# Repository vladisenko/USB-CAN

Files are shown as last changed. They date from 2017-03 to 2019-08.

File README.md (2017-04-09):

# USB-CAN
Yet another USB-CAN adapter. Device based on STM32F072C8T6 mcu with USB and CAN peripherals. As the galvanic isolated CAN transceiver is used ISO1050 from TI. Boards communicate with PC by Virtual COM port with LAWICEL protocol.
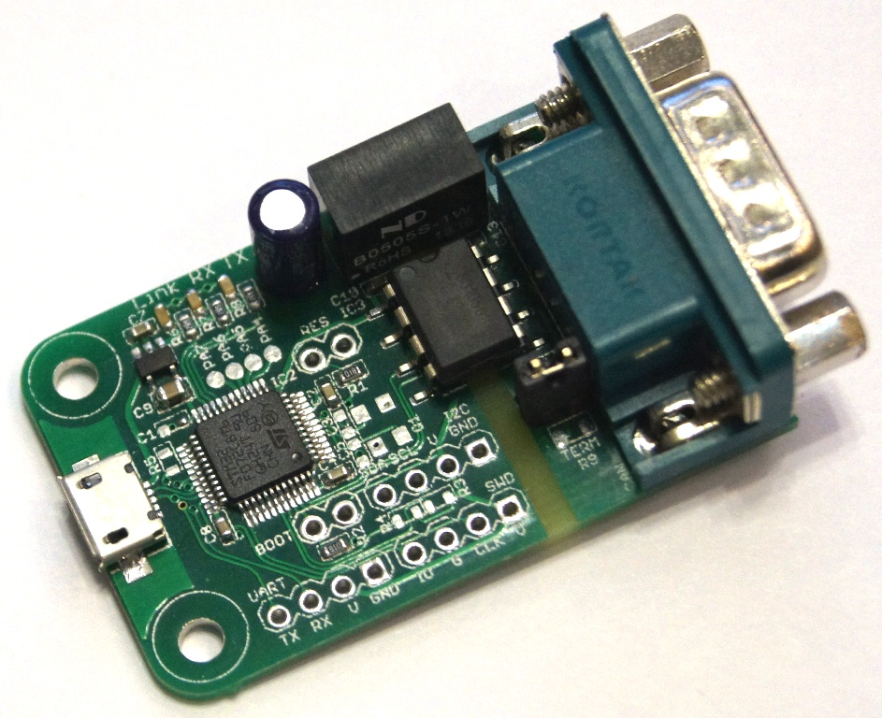
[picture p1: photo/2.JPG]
USB-CAN adapter


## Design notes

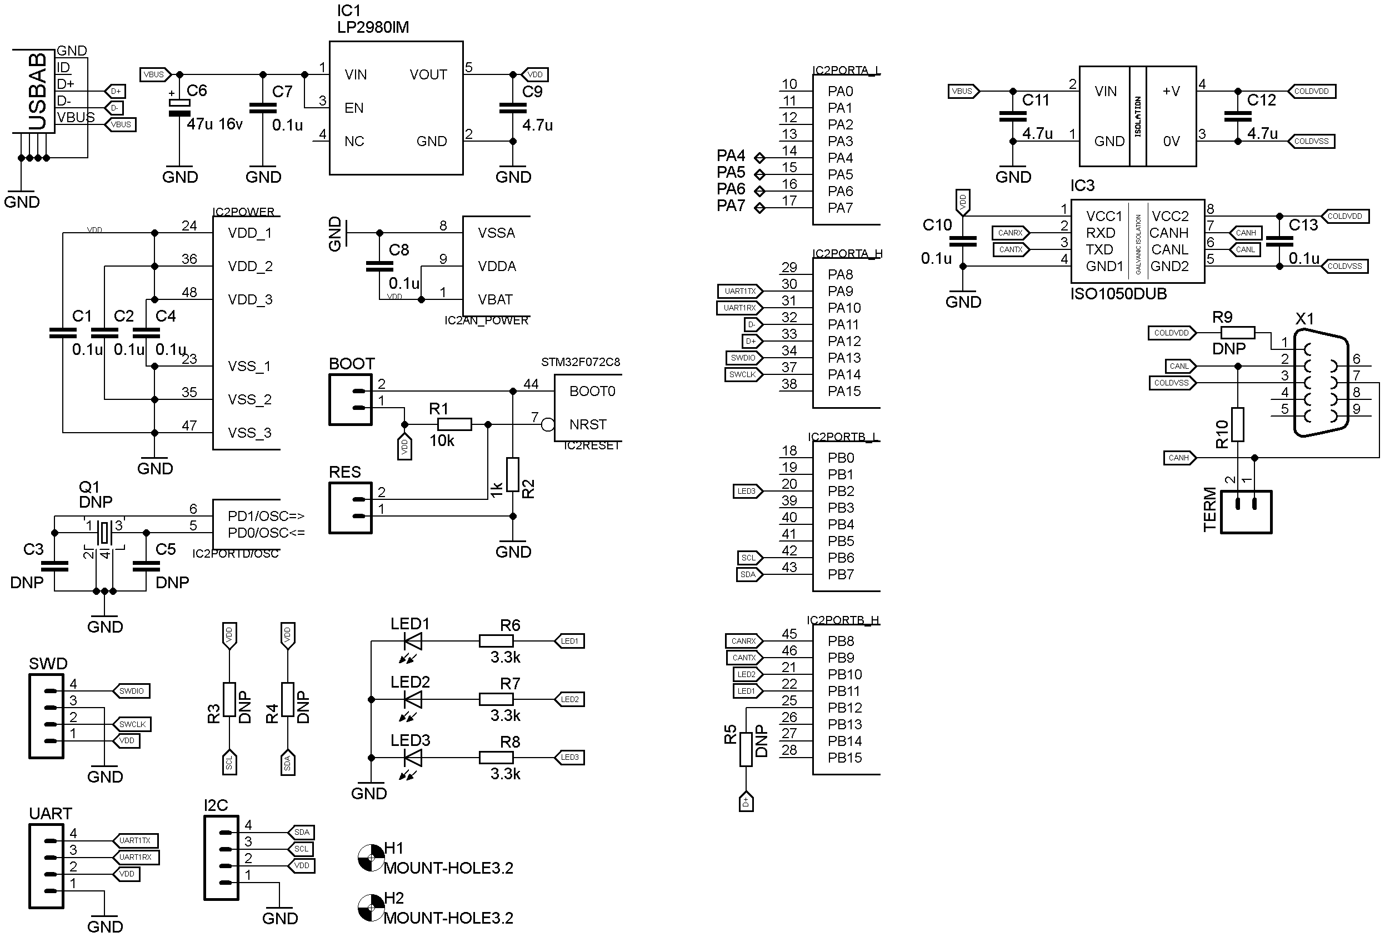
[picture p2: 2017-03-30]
hw/schematic.png

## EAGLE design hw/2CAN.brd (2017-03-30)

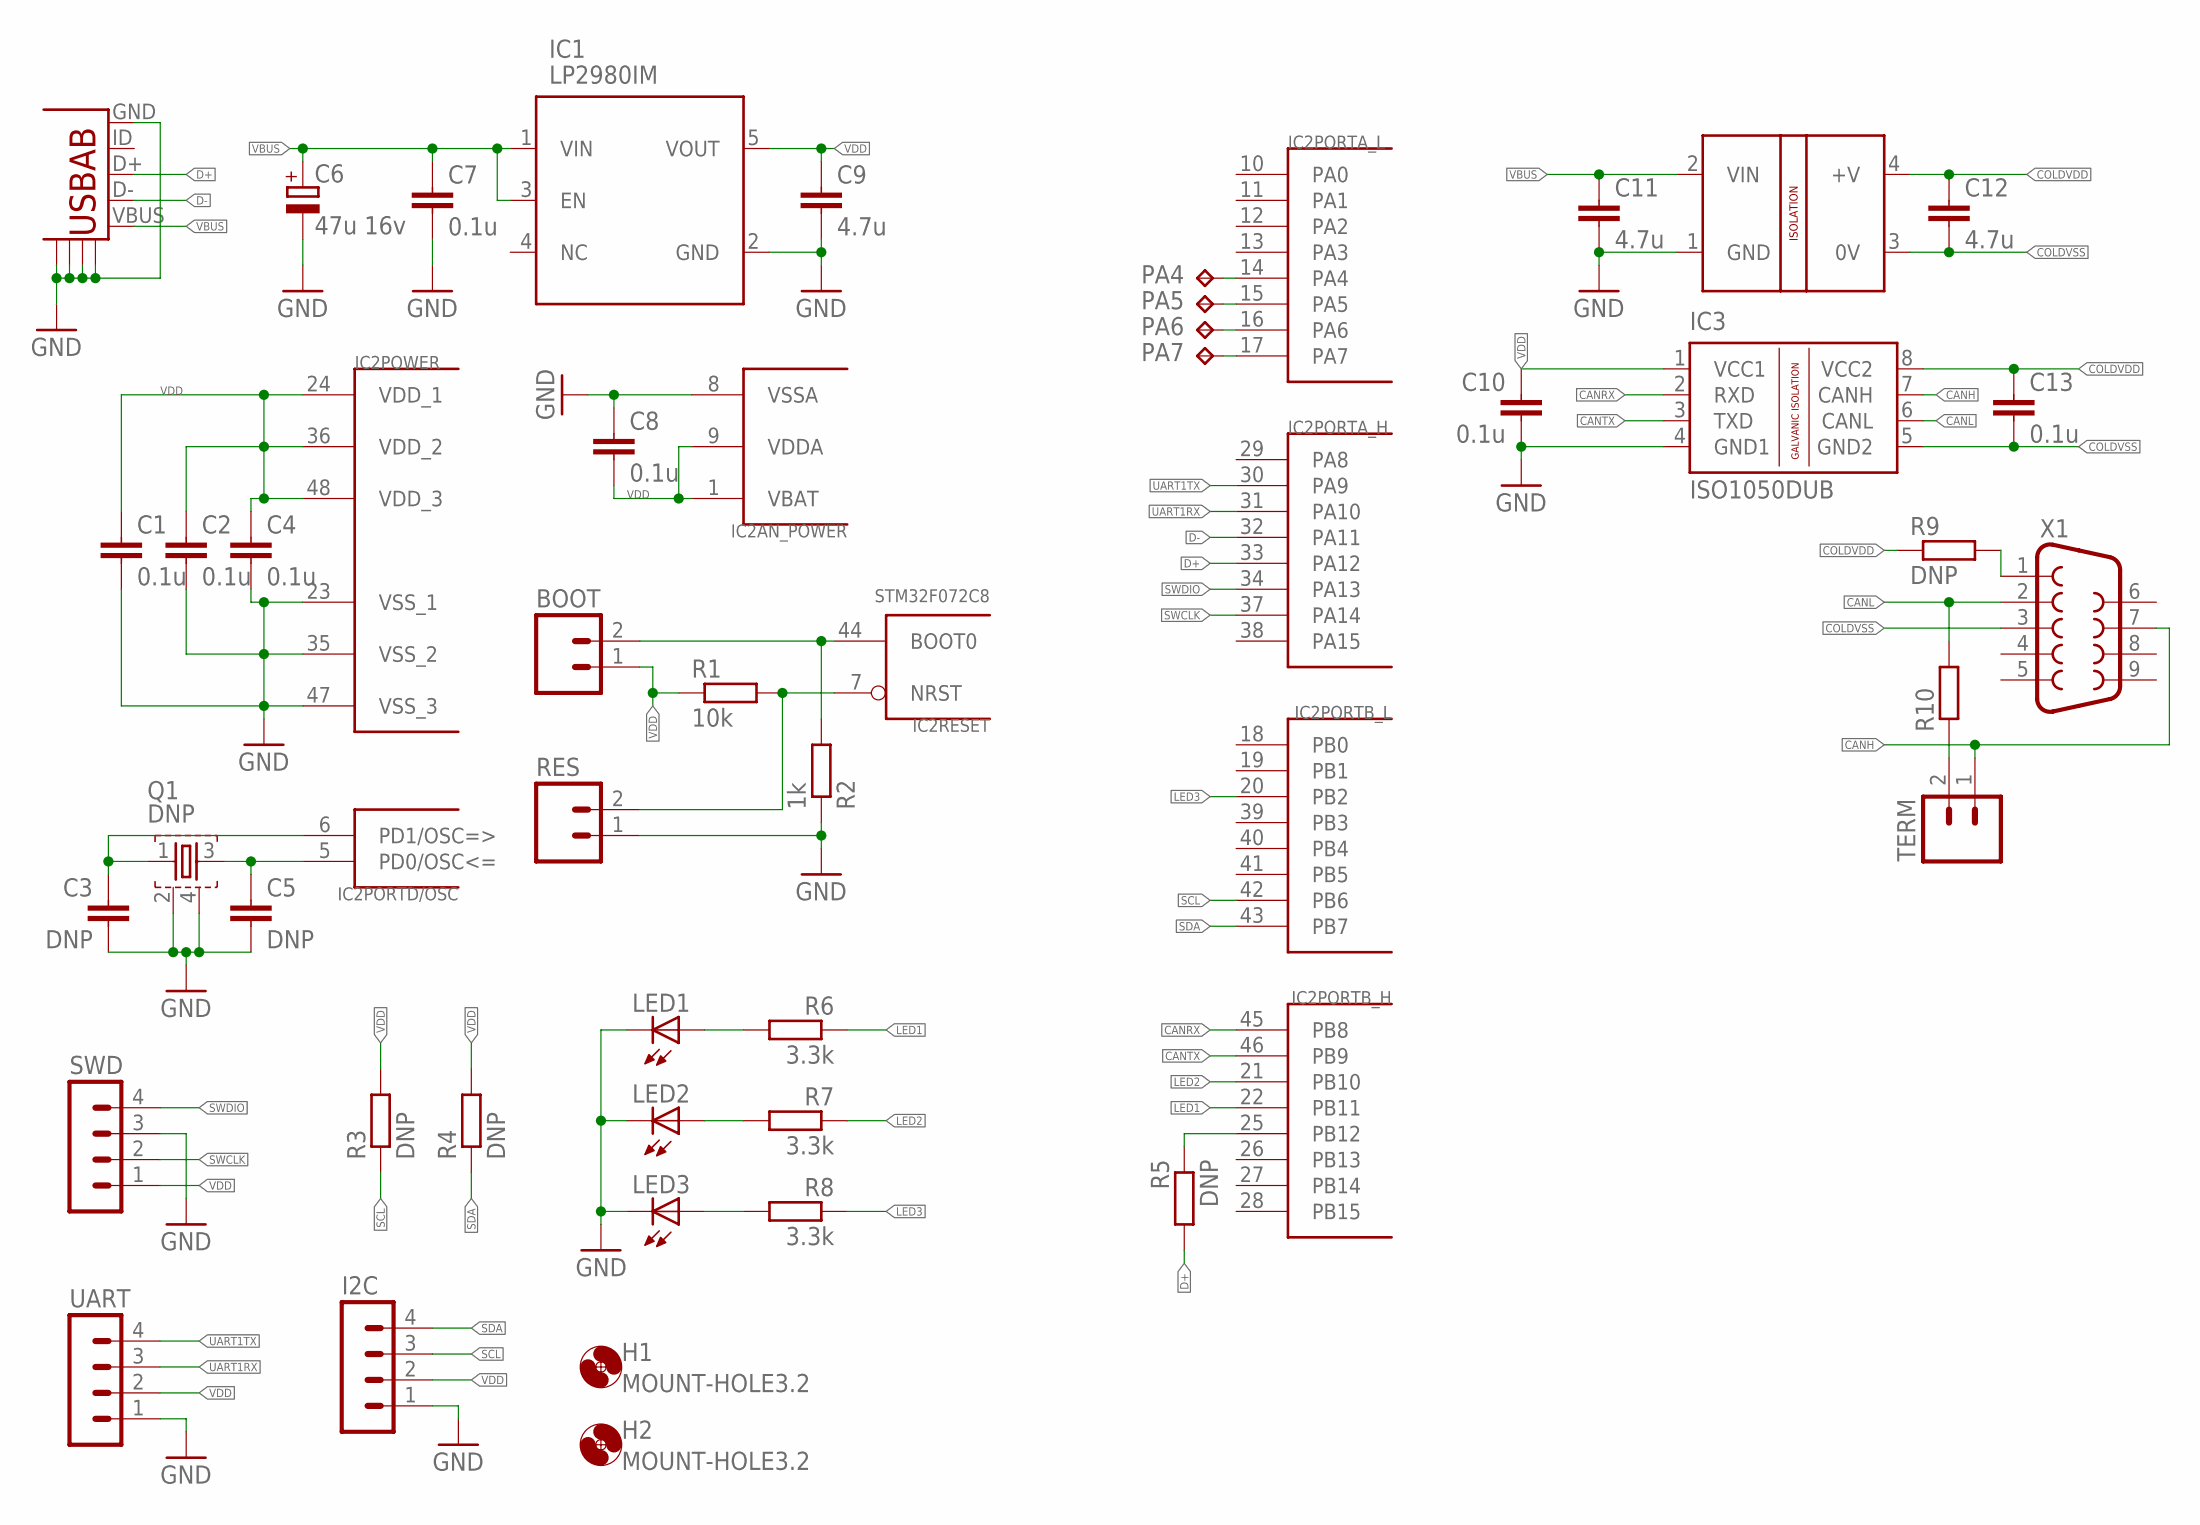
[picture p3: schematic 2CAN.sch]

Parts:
BOOT: M02PTH; 1X02
C1, C2, C4, C7, C8, C10, C13: 0.1u; C0603
C3, C5: DNP; C0603
C6: 47u 16v; E2-5
C9, C11, C12: 4.7u; C0805
H1, H2: MOUNT-HOLE3.2; 3,2
I2C: MA04-1
IC1: LP2980IM; SOT23-5L
IC2: STM32F072C8; TQFP48
IC3: ISO1050DUB; DUB-R-PDSO-G8
LED1, LED2, LED3: LEDSML0603; SML0603
PA4, PA5, PA6, PA7: TPB1,27; B1,27
Q1: DNP; FA-20H
R1: 10k; R0603
R2: 1k; R0603
R3, R4, R5: DNP; R0603
R6, R7, R8: 3.3k; R0603
R9: DNP; R0805
R10: R-EU_R0805; R0805
RES: M02PTH; 1X02
SWD: MA04-1
TERM: M02PTH; 1X02
U$1: USB_AB; USB-AB-MICRO-SMD
U$2: B0505SV; B0505S_V
UART: MA04-1
X1: DB9MALE; DB9_MALE

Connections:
CANH: IC3.7 (CANH), TERM.1, X1.7
CANL: IC3.6 (CANL), R10.2, X1.2
CANRX: IC2.45 (PB8), IC3.2 (RXD)
CANTX: IC2.46 (PB9), IC3.3 (TXD)
COLDVDD: C12.1, C13.1, IC3.8 (VCC2), R9.1, U$2.4 (+V)
COLDVSS: C12.2, C13.2, IC3.5 (GND2), U$2.3 (0V), X1.3
D+: IC2.33 (PA12), R5.2, U$1.D+
D-: IC2.32 (PA11), U$1.D-
GND: C1.2, C2.2, C3.2, C4.2, C5.2, C6.-, C7.2, C8.1, C9.2, C10.2, C11.2, I2C.1, IC1.2 (GND), IC2.8 (VSSA), IC2.23 (VSS_1), IC2.35 (VSS_2), IC2.47 (VSS_3), IC3.4 (GND1), LED1.C, LED2.C, LED3.C, Q1.2, Q1.4, R2.1, RES.1, SWD.3, U$1.GND, U$1.GND@1, U$1.GND@2, U$1.GND@3, U$1.GND@4, U$2.1 (GND), UART.1
LED1: IC2.22 (PB11), R6.1
LED2: IC2.21 (PB10), R7.1
LED3: IC2.20 (PB2), R8.1
unnamed: IC2.7 (NRST), R1.2, RES.2
unnamed: BOOT.2, IC2.44 (BOOT0), R2.2
unnamed: R9.2, X1.1
unnamed: LED1.A, R6.2
unnamed: LED2.A, R7.2
unnamed: LED3.A, R8.2
unnamed: R10.1, TERM.2
unnamed: C5.1, IC2.5 (PD0/OSC<=), Q1.3
unnamed: C3.1, IC2.6 (PD1/OSC=>), Q1.1
unnamed: IC2.14 (PA4), PA4.TP
unnamed: IC2.15 (PA5), PA5.TP
unnamed: IC2.16 (PA6), PA6.TP
unnamed: IC2.17 (PA7), PA7.TP
SCL: I2C.3, IC2.42 (PB6), R3.1
SDA: I2C.4, IC2.43 (PB7), R4.1
SWCLK: IC2.37 (PA14), SWD.2
SWDIO: IC2.34 (PA13), SWD.4
UART1RX: IC2.31 (PA10), UART.3
UART1TX: IC2.30 (PA9), UART.4
USBPU: IC2.25 (PB12), R5.1
VBUS: C6.+, C7.1, C11.1, IC1.1 (VIN), IC1.3 (EN), U$1.VBUS, U$2.2 (VIN)
VDD: BOOT.1, C1.1, C2.1, C4.1, C8.2, C9.1, C10.1, I2C.2, IC1.5 (VOUT), IC2.1 (VBAT), IC2.9 (VDDA), IC2.24 (VDD_1), IC2.36 (VDD_2), IC2.48 (VDD_3), IC3.1 (VCC1), R1.1, R3.2, R4.2, SWD.1, UART.2

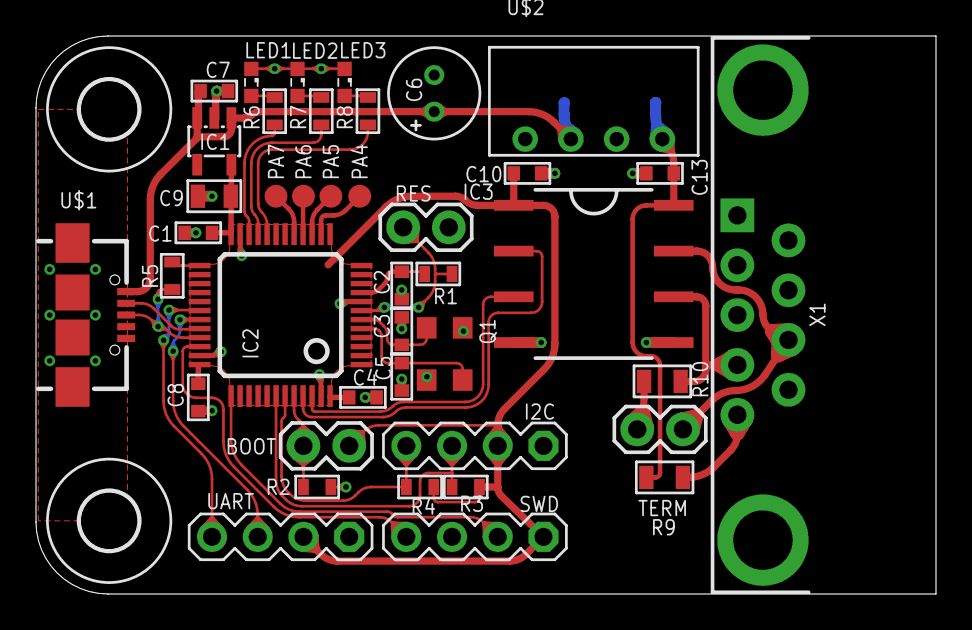
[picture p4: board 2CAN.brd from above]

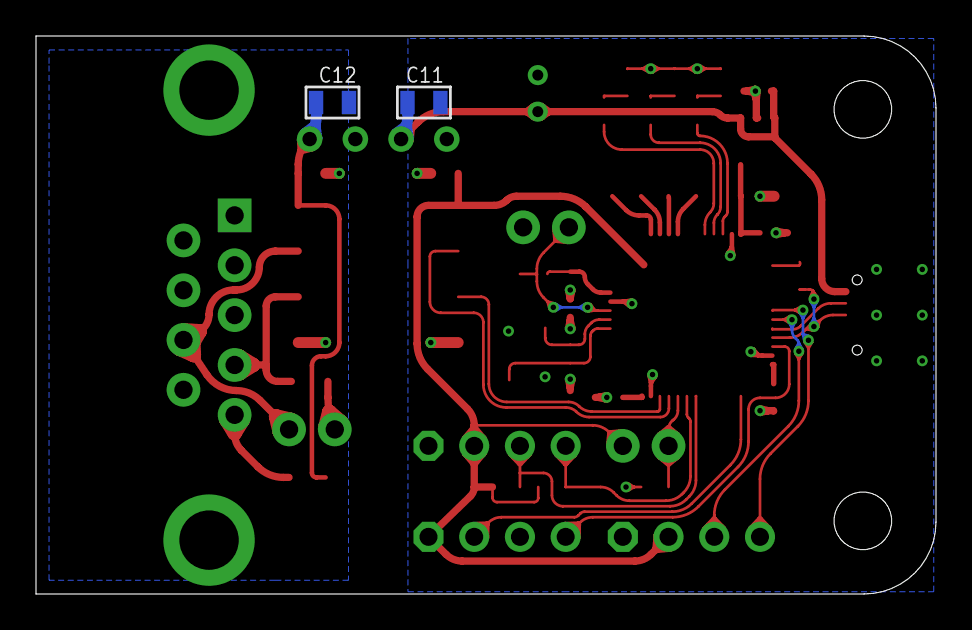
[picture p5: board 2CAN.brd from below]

Board: 2 copper layers, 50.0 x 31.0 mm, 45 parts (2 on the bottom side), 34 nets.

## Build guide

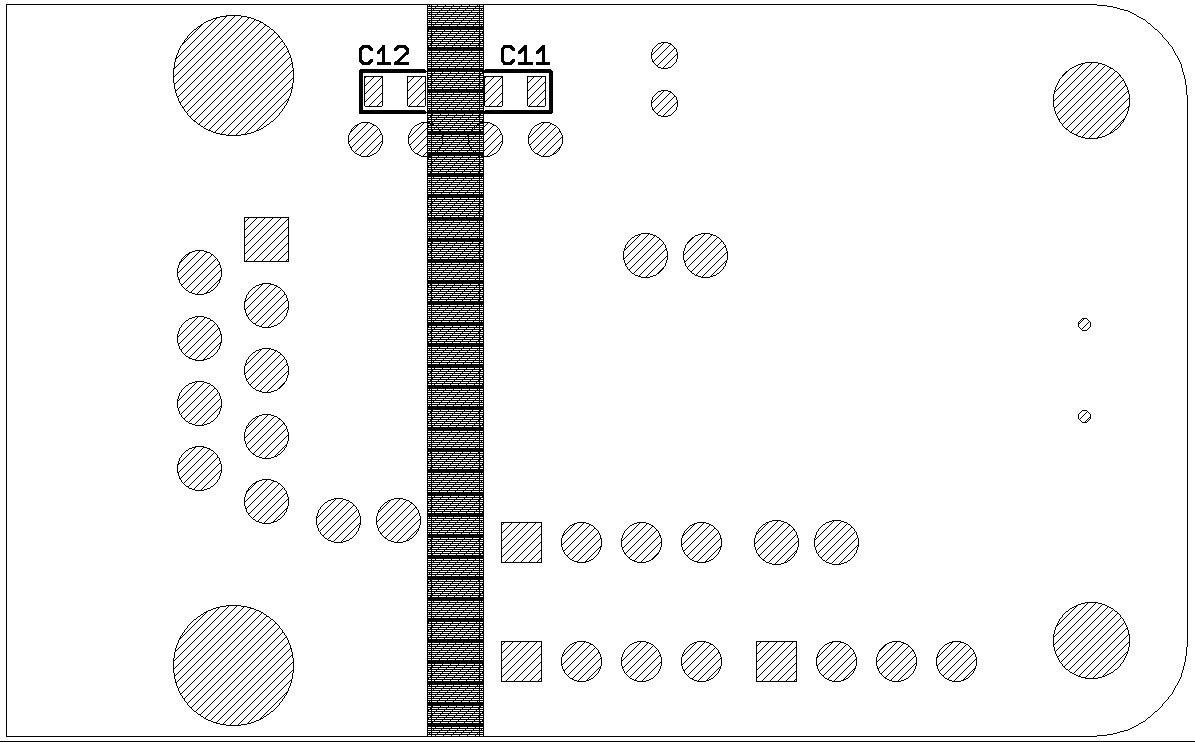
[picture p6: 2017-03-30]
hw/assembly-bottom.png

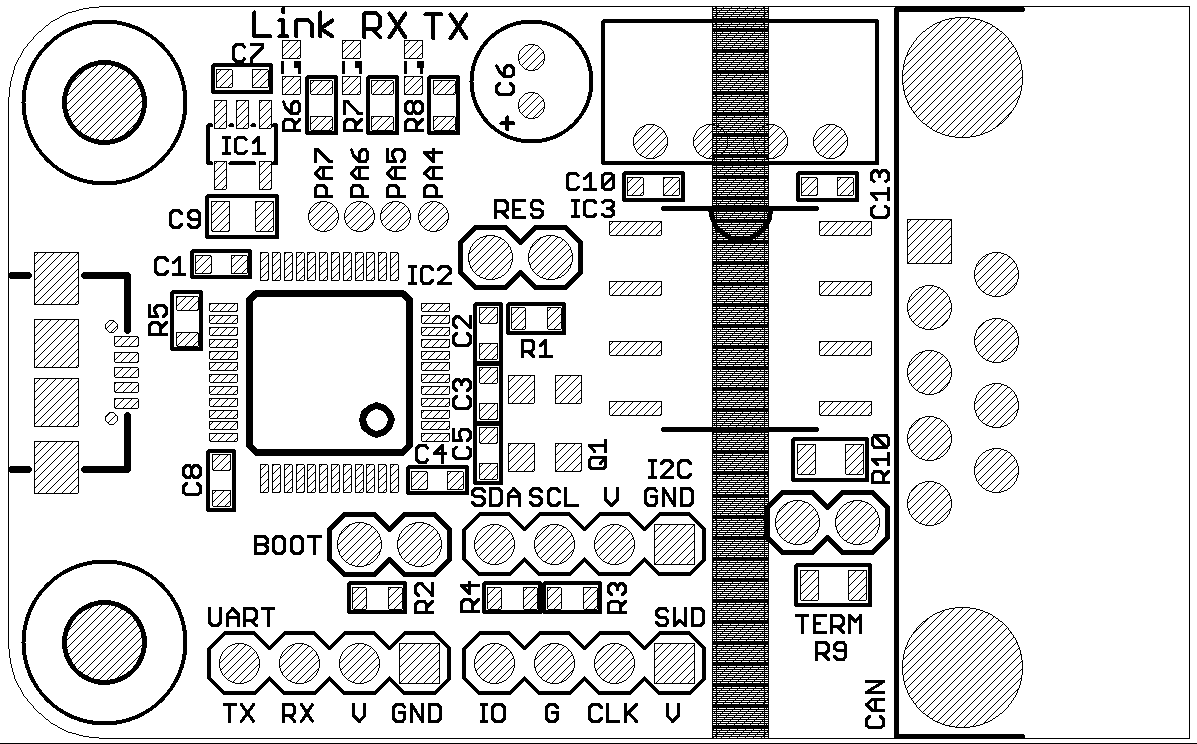
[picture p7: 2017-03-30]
hw/assembly-top.png

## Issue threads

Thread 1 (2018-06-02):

Manual can bitrate.

Memfispro, 2018-06-02:
Здравствуйте! Я недавно повторил проект и мне понравился. Спасибо огромное.
Вопрос: как мне выставит 83.33 и 33.33?
Я пробовал с калькулятором у меня не получилось

vladisenko, 2018-06-04:
Здравствуйте.
Расчет константы для произвольного битрейта довольно мудреный получился. Он отличает от оригинального адаптера. Позже постараюсь сделать калькулятор. Для 83,3k константа равна 8A2F, а для 33,3k - AE5F.
Рекомендую обновить прошивку на последнюю - там исправлена работа виртуального последовательного порта.

vladisenko, 2018-06-13:
Нет, еще не было необходимости анализировать LIN шину. В планах сделать новую ревизию печатной платы и добавить такую возможность.

Memfispro, 2018-10-10:
Скажите пожалуйста по каким формулам рассчитывается другие скорости can адаптера. С Уважением!

vladisenko, 2018-10-15:
Я загрузил калькулятор для расчета битрейта. Попробуйте его использовать.
https://github.com/vladisenko/USB-CAN/blob/master/mask%20and%20custom%20bitrate.xlsx

Memfispro, 2018-10-16:
Спасибо. Умно сделано однако.

Memfispro, 2019-02-18:
Привет. На схеме я видел uart rx tx если на этот выход подключить bluetooth адаптер будет работат как bluetooth serial?

vladisenko, 2019-03-05:
Нет, программно UART не задействован, надо править исходный код.

Memfispro, 2019-03-05:
Понятно. Потом при тестирование адаптера не принимая пакета если отправить данные то после третьего отправки данных tx светодиод постоянно горит как будто зависает.
С Уважением.

vladisenko, 2019-03-07:
Спасибо, действительно была ошибка. Исправил.

Memfispro, 2019-03-07:
Быстренько проверил прошивку теперь после третьего отправки данных tx светодиод не реагирует. (Нет вспишки)

vladisenko, 2019-03-07:
Это нормально. Если CAN шина не подключена, то и ACK некому выставлять, а следовательно, и сообщение считается не отправленным. В микроконтроллере включена повторная передача сообщения до успешной передачи. А так как всего три аппаратных mailbox-а, то четвертое сообщение уже не передается. С подключенной шиной все будет нормально отправляться.

Memfispro, 2019-03-07:
Теперь стало понятно. Спасибо.

iDoka, 2019-08-06:
> https://github.com/uCAN-LIN/LinUSBConverter
> Сделали универсально.

в чём универсальность?
там отдельные репо под LIN адаптер и под CAN

....а ведь могли бы!!!!!
могли бы поднять композитное USB-устройство с двумя CDC!!!
и под капотом одного STM32 были бы независимые CAN & LIN

под F0x2 не встречал композита на 2хCDC, а вот под F10х есть такой пример на гитхаб

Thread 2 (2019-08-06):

FW requirement

iDoka, 2019-08-06:
What is memory consumptions for FW?
both RAM and FLASH.

My intention: can I use F042 instread of F072 series?

Thanks

vladisenko, 2019-08-06:
Hi.

About 13.4 KB of Flash and 13.3 KB of RAM are currently used. RAM consumption can be reduced by decreasing size of CDC buffers. I think the F042 series can be used, but pin remapping should be used for the TSSOP package.

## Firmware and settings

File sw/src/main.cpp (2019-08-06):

#include <stdio.h>
#include <stdlib.h>
#include <string.h>
#include <ctype.h>

#include "stm32f0xx.h"

#include "can.hpp"
#include "fifo.hpp"

extern "C" 
{
#include "usbd_cdc_core.h"
#include "usbd_cdc_vcp.h"
#include "usbd_usr.h"
};


enum {
  GetVersionSW    = 'v',
  GetVersionHW    = 'V',
  GetStatus       = 'F',
  OpenCAN         = 'O',
  OpenCANLoopback = 'l',
  OpenCANListen   = 'L',
  CloseCAN        = 'C',
  SetTimestamping = 'Z',
  SetBitrate      = 'S',
  SetBitrateCustom= 's',
  SetFilterMask   = 'm',
  SetFilterCode   = 'M',
  SendStd         = 't',
  SendStdRTR      = 'r',
  SendExt         = 'T',
  SendExtRTR      = 'R'
};


USB_CORE_HANDLE  USB_Device_dev;

FIFO<uint8_t, 4096> rxfifo; 
FIFO<uint8_t, 4096> txfifo;


uint16_t VCP_callback(uint8_t* Buf, uint32_t Len)
{
  while (Len--) rxfifo.push(*Buf++); // TODO: control overflow!
  return USBD_OK;
}


static inline void VCP_PutStr (const char* str)
{
  VCP_DataTx((uint8_t*)str, strlen(str));
}


static inline CANbus::Bitrate GetBitrate (uint8_t ch)
{
  switch(ch)
  {
    case '0': return CANbus::Bitrate::br10kbit; 
    case '1': return CANbus::Bitrate::br20kbit; 
    case '2': return CANbus::Bitrate::br50kbit; 
    case '3': return CANbus::Bitrate::br100kbit; 
    case '4': return CANbus::Bitrate::br125kbit; 
    case '5': return CANbus::Bitrate::br250kbit; 
    case '6': return CANbus::Bitrate::br500kbit; 
    case '7': return CANbus::Bitrate::br800kbit; 
    case '8': default: return CANbus::Bitrate::br1Mbit; 
  }
}  


static inline uint8_t char_to_hex (char c)
{
  uint8_t res;
  if (isdigit(c))
    res = c - '0';
  else if (c >= 'a' && c <= 'f')
    res = c - 'a' + 10;
  else if (c >= 'A' && c <= 'F')
    res = c - 'A' + 10;
  else
    res = 0xFF;
  return res;
}


static inline char hex_to_char (uint8_t hex)
{
  const char tbl[16] = {'0', '1', '2', '3',
                        '4', '5', '6', '7',
                        '8', '9', 'A', 'B',
                        'C', 'D', 'E', 'F'};
  return tbl[hex & 0x0F];
}


static inline uint32_t get_word (void)
{
  uint8_t tmp;
  uint8_t i = 8;
  uint32_t result = 0;
  do
  {
    while (false == rxfifo.pop(tmp)){};
    result = (result << 4) | char_to_hex(tmp);
  } while ( tmp != '\r' && --i);
  return  result;
}


static inline uint32_t GetBitrateCustom (void)
{
  uint8_t tmp;
  uint8_t i = 4;
  uint32_t btr = 0;

  do
  {
    while (false == rxfifo.pop(tmp)){};
    btr = (btr << 4) | char_to_hex(tmp);
  } while ( tmp != '\r' && --i);
  btr = (btr & 0x01FF) | ((btr & 0xFE00) << 7);
  return  btr;
}


CANbus::Status SendCANMsg (uint8_t type)
{
  CANbus::TxMsg msg;
  msg.Id = 0;
  msg.IDE = (type == 'T' || type == 'R') ? true : false; 
  msg.RTR = (type == 'r' || type == 'R') ? true : false;
  memset(msg.Data8, 0, sizeof(msg.Data8));

  uint32_t idx = 0;

  for (uint32_t i = (msg.IDE) ? 0 : 5; true; i++) // if STD use only 3 chars for ID
  {
    uint8_t tmp;
    while (false == rxfifo.pop(tmp)){};
    if (tmp == '\r') return CANbus::Status::Error; // FIXME: rewrite this 
    if (i < 8)                            // get ID
    {
      msg.Id = (msg.Id << 4) | char_to_hex(tmp);
    }
    else if (i < 9)                       // get DLC
    {
      msg.DLC = char_to_hex(tmp);
      if ((msg.RTR) || (msg.DLC == 0)) break; // if this is remote frame or zero data length, no need to send data
    }
    else                                  // get DATA
    {
      msg.Data8[idx >> 1] <<= 4;
      msg.Data8[idx >> 1] |= char_to_hex(tmp);
      if (++idx >= 2*msg.DLC) break;
    }
  }
  return CANbus::send(msg);
}  


void ReceiveCANMsg (CANbus::RxMsg &msg) // FIXME: rewrite function
{
  uint8_t tmp[40];
  uint32_t len = 0;
  
  if (msg.IDE)  // if Ext frame
  {
    tmp[len++] = (msg.RTR) ? 'R' : 'T';
    tmp[len++] = hex_to_char(msg.Id >> 28); 
    tmp[len++] = hex_to_char(msg.Id >> 24);
    tmp[len++] = hex_to_char(msg.Id >> 20);    
    tmp[len++] = hex_to_char(msg.Id >> 16); 
    tmp[len++] = hex_to_char(msg.Id >> 12);
    tmp[len++] = hex_to_char(msg.Id >> 8); 
    tmp[len++] = hex_to_char(msg.Id >> 4);
    tmp[len++] = hex_to_char(msg.Id >> 0); 
  }
  else
  {
    tmp[len++] = (msg.RTR) ? 'r' : 't';
    tmp[len++] = hex_to_char(msg.Id >> 8); 
    tmp[len++] = hex_to_char(msg.Id >> 4);
    tmp[len++] = hex_to_char(msg.Id >> 0);
  }

  tmp[len++] = hex_to_char(msg.DLC >> 0);
  uint16_t i = 0;
  while (!msg.RTR && i < msg.DLC)
  {
  tmp[len++] = hex_to_char(msg.Data8[i] >> 4);
  tmp[len++] = hex_to_char(msg.Data8[i] >> 0);
  i++;
  }

  if (CANbus::timestamp())
  {
    tmp[len++] = hex_to_char( msg.Time >> 12);
    tmp[len++] = hex_to_char( msg.Time >> 8);
    tmp[len++] = hex_to_char( msg.Time >> 4);
    tmp[len++] = hex_to_char( msg.Time >> 0);
  }

  tmp[len++] = '\r';	
 
  for (uint8_t i = 0; i < len; i++)
  {
    txfifo.push(tmp[i]);
  }
}


/*********************************************************************
*
*       main()
*
*  Function description
*   Application entry point.
*/
int main(void)
{
  RCC->AHBENR |= RCC_AHBENR_GPIOBEN;
  GPIOB->MODER &= ~GPIO_MODER_MODER10;
  GPIOB->MODER |= GPIO_MODER_MODER10_0; // output

  CANbus::init();
  CANbus::set_rx_cb(ReceiveCANMsg);

  USBD_Init(&USB_Device_dev, &USR_desc, &USBD_CDC_cb, &USR_cb);
  
  while (1)
  {
    if (!rxfifo.empty())
    {
      CANbus::Status st = CANbus::Status::Error;
      uint8_t tmp;
      rxfifo.pop(tmp);
      bool skip_resp = false;
      
      switch (tmp)
      {
        case GetVersionSW: VCP_PutStr("vSTM32"); st = CANbus::Status::Ok; break;
        case GetVersionHW: VCP_PutStr("V0102"); st = CANbus::Status::Ok; break;
        case GetStatus:    VCP_PutStr("F00"); st = CANbus::Status::Ok; break;      // TODO: add response
        case OpenCAN:
          txfifo.clear();
          st = CANbus::open(CANbus::OpenMode::Normal);
          break;
        case OpenCANLoopback: st = CANbus::open(CANbus::OpenMode::LoopBack); break;
        case OpenCANListen:   st = CANbus::open(CANbus::OpenMode::ListenOnly); break;
        case CloseCAN:        st = CANbus::close(); break;       
        case SetTimestamping: 
          while (false == rxfifo.pop(tmp)){};
          st = CANbus::timestamp((tmp=='0') ? false : true);
          break;
        case SetBitrate:
          while (false == rxfifo.pop(tmp)){};
          st = CANbus::bitrate(GetBitrate(tmp));
          break;
        case SetBitrateCustom:
          st = CANbus::bitrate(GetBitrateCustom());
          break;
        case SendStd: case SendStdRTR:
          st = SendCANMsg(tmp);
          if (st==CANbus::Status::Ok) VCP_PutStr("z");
          break;		
        case SendExt: case SendExtRTR:
          st = SendCANMsg(tmp);
          if (st==CANbus::Status::Ok) VCP_PutStr("Z");
          break;		
        case SetFilterCode:
          st = CANbus::filtercode(get_word());
          break;
        case SetFilterMask:
          st = CANbus::filtermask(get_word());
          break;
        default:
          st = CANbus::Status::Ok;
          skip_resp = true;
          break;
      }
      
      if (!skip_resp)
      {
        VCP_PutStr ((st==CANbus::Status::Ok) ? "\r" : "\a");
        skip_resp = false;
      }
    }

    while(1)
    {
      uint8_t tmp;
      if (txfifo.front(tmp) && (VCP_DataTx(&tmp, 1) == 1)) {
        txfifo.pop(tmp); /* remove char from queue only if it successfully written to VCP */
      } else {
        break;
      }
    }
  }
}

/*************************** End of file ****************************/

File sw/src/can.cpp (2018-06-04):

#include "stm32f0xx.h"
#include "can.hpp"
#include "fifo.hpp"
#include "timer_led.hpp"


extern "C" void CEC_CAN_IRQHandler (void);

using CANbus::Status;
using CANbus::OpenMode;
using CANbus::Bitrate;
using CANbus::RxMsg;
using CANbus::TxMsg;


static TimerLed timled;
static bool timestamping = false;
static CANbus::RxCallback rx_cb = nullptr;
static bool isopen = false;
static uint32_t btr_reg = static_cast<uint32_t>(Bitrate::br1Mbit);


Status CANbus::init (void)
{
  RCC->AHBENR |= RCC_AHBENR_GPIOBEN;
  GPIOB->MODER &= ~(GPIO_MODER_MODER9 | GPIO_MODER_MODER8);
  GPIOB->MODER |= GPIO_MODER_MODER9_1 | GPIO_MODER_MODER8_1;
  GPIOB->AFR[1] &= ~0x000000FF;
  GPIOB->AFR[1] |=  0x00000044;

  RCC->APB1ENR |= RCC_APB1ENR_CANEN;
  CAN->MCR = CAN_MCR_SLEEP | CAN_MCR_ABOM | CAN_MCR_TXFP;

  CAN->FMR |= CAN_FMR_FINIT; 
  CAN->FM1R = 0;                    // 0: Two 32-bit registers of filter bank x are in Identifier Mask mode.
  CAN->FS1R = CAN_FS1R_FSC0;        // 1: Single 32-bit scale configuration
  CAN->FFA1R = 0;                   // 0: Filter assigned to FIFO 0
  CAN->FA1R = CAN_FA1R_FACT0;       // 1: Filter is active
  CAN->sFilterRegister[0].FR1 = 0;  // ID
  CAN->sFilterRegister[0].FR2 = 0;  // MASK  
  CAN->FMR &= ~(uint32_t)CAN_FMR_FINIT;

  timled.init();

  return Status::Ok;
}


Status CANbus::filtermask (uint32_t msk)
{
  CAN->FMR |= CAN_FMR_FINIT; 
  CAN->sFilterRegister[0].FR2 = ~msk; // MASK  
  CAN->FMR &= ~(uint32_t)CAN_FMR_FINIT;
  return Status::Ok;
}


Status CANbus::filtercode (uint32_t code)
{
  CAN->FMR |= CAN_FMR_FINIT; 
  CAN->sFilterRegister[0].FR1 = code; // ID  
  CAN->FMR &= ~(uint32_t)CAN_FMR_FINIT;
  return Status::Ok;
}


Status CANbus::bitrate (Bitrate br)
{
  return bitrate(static_cast<uint32_t>(br));
}


Status CANbus::bitrate (uint32_t btr)
{
  btr_reg &= ~(CAN_BTR_BRP | CAN_BTR_TS1 | CAN_BTR_TS2 | CAN_BTR_SJW);
  btr_reg |= btr & (CAN_BTR_BRP | CAN_BTR_TS1 | CAN_BTR_TS2 | CAN_BTR_SJW);
  
  // FIXME: check busy?
  if (isopen)
  {
    CAN->MCR |= CAN_MCR_INRQ;
    while (!(CAN->MSR & CAN_MSR_INAK));

    CAN->BTR = btr_reg;
  
    CAN->MCR &= ~((uint32_t)CAN_MCR_INRQ);
    while (CAN->MSR & CAN_MSR_INAK);
  }

  return Status::Ok;
}


Status CANbus::open (OpenMode mode)
{
  CAN->MCR |= CAN_MCR_RESET;
  while(CAN->MCR & CAN_MCR_RESET);

  CAN->MCR |= CAN_MCR_INRQ;
  while (!(CAN->MSR & CAN_MSR_INAK));

  btr_reg &= ~(CAN_BTR_LBKM | CAN_BTR_SILM);
  switch (mode)
  {
    case OpenMode::Normal: break;
    case OpenMode::LoopBack: btr_reg |= CAN_BTR_LBKM; break;
    case OpenMode::ListenOnly: btr_reg |= CAN_BTR_SILM; break;
  }
  CAN->BTR = btr_reg;

  CAN->MCR &= ~(uint32_t)CAN_MCR_INRQ;
  while (CAN->MSR & CAN_MSR_INAK);
  
  CAN->MCR &= ~(uint32_t)CAN_MCR_SLEEP;

  CAN->IER |= CAN_IER_FMPIE0;
  NVIC_SetPriority(CEC_CAN_IRQn, 1);
  NVIC_EnableIRQ(CEC_CAN_IRQn);
  
  isopen = true;
  timled.link(true);
  return Status::Ok;
}


Status CANbus::close (void)
{
  // FIXME: check busy?
  CAN->MCR |= CAN_MCR_SLEEP;
    
  NVIC_DisableIRQ(CEC_CAN_IRQn);

  isopen = false;
  timled.link(false);
  return Status::Ok;
}


Status CANbus::timestamp (bool state)
{
  timestamping = state;
  return Status::Ok;
}


bool CANbus::timestamp (void)
{
  return timestamping;
}


Status CANbus::send (TxMsg &msg)
{
  Status result = Status::Error;
  
  if (CAN->TSR & (CAN_TSR_TME))
  {
    uint32_t mb = (CAN->TSR & CAN_TSR_CODE) >> 24;

    CAN->sTxMailBox[mb].TDTR = msg.DLC;
    CAN->sTxMailBox[mb].TDLR = msg.Data32[0];
    CAN->sTxMailBox[mb].TDHR = msg.Data32[1];

    uint32_t tmp;
    tmp = msg.Id << (msg.IDE ? 3 : 21);
    tmp |= msg.IDE ? CAN_TI0R_IDE : 0;
    tmp |= msg.RTR ? CAN_TI0R_RTR : 0;
    CAN->sTxMailBox[mb].TIR = tmp | CAN_TI0R_TXRQ;
    
    timled.tx_blink(5);
    result = Status::Ok;
  }

  return result;
}


Status CANbus::set_rx_cb(RxCallback cb)
{
  Status result = Status::Error;
  if (cb != nullptr)
  {
    rx_cb = cb;
    result = Status::Ok;
  }
  return result;
}


void CEC_CAN_IRQHandler (void)
{
  
  // TODO: add error handling

  if (CAN->RF0R & CAN_RF0R_FMP0)
  {
    RxMsg msg;
    msg.Time = timled.value();
    msg.IDE = (CAN->sFIFOMailBox[0].RIR & CAN_RI0R_IDE) ? true : false;
    msg.Id = CAN->sFIFOMailBox[0].RIR >> ((msg.IDE) ? 3 : 21);
    msg.RTR = (CAN->sFIFOMailBox[0].RIR & CAN_RI0R_RTR) ? true : false;
    msg.DLC = CAN->sFIFOMailBox[0].RDTR & CAN_RDT0R_DLC;
    msg.Data32[0] = CAN->sFIFOMailBox[0].RDLR;
    msg.Data32[1] = CAN->sFIFOMailBox[0].RDHR;

    CAN->RF0R |= CAN_RF0R_RFOM0;
    timled.rx_blink(5);
    if (rx_cb != nullptr)
    {
      rx_cb(msg);
    }
  }
}

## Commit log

2017-03-30 add hardware
    [2CAN.brd, 2CAN.sch]
2018-10-15 add bitrate calculator
    [mask and custom bitrate.xlsx]
2019-03-05 fix transmitting of IDE frames
    [main.cpp]
2019-03-07 fix led issue
2019-08-06 fix issue with sending zero length data frame
    [main.cpp]
